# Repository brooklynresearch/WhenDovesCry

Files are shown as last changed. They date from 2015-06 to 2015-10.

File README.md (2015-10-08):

# ToniDove
Robotic Control and Communication.  

## OSC Messaging
The OSC messaging protocol to control the servos.
The current two messages to control the shoulder of the robot arm are `/sPitch` and `/sRoll`.  The Pitch message controlling the base rotation (single servo), and the Roll message controlling the swing angle (two servos).  Each message requires two integer arguments.  
### Arguments
`servoPosition` which has a range of 0 - 2047
 `servoSpeed` which has a range of 1 - inf. 
 `servoSpeed` is roughly in milliseconds and the value given is the amount of time you gave to go from currentPosition to the previously supplied servePosition (i.e. the larger the value given, the slower it will move)
### OSC Message Orientation
```{r, engine='bash', count_lines}
/sPitch servoPosition servoSpeed
/sRoll servoPosition servoSpeed
```
### OSC Example
```{r, engine='bash', count_lines}
/sPitch 512 18
/sRoll 1024 100
```
Current IP address is 192.168.0.200
Current listening PORT is 12345

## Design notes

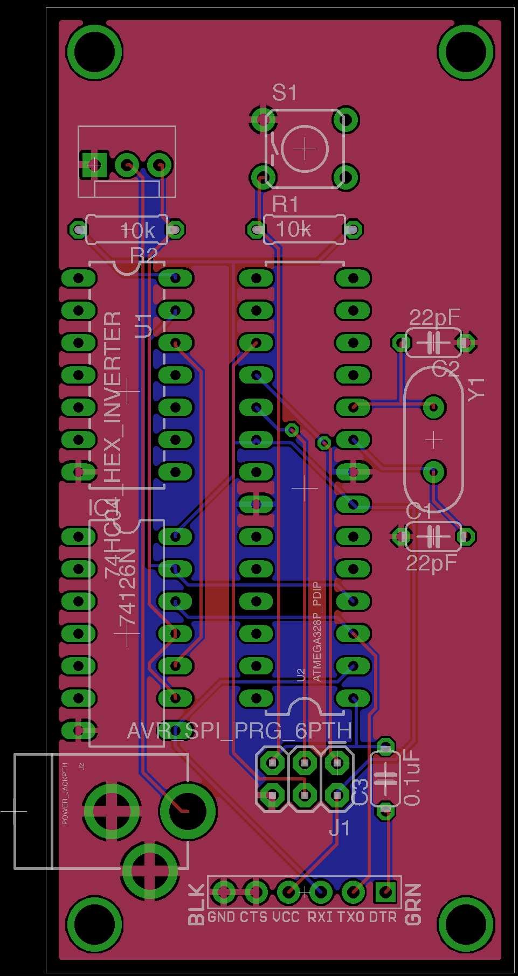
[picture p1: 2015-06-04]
ServoControl/Eagle/Arduino/Preliminary/DynamixelController_PreliminaryDesign.png

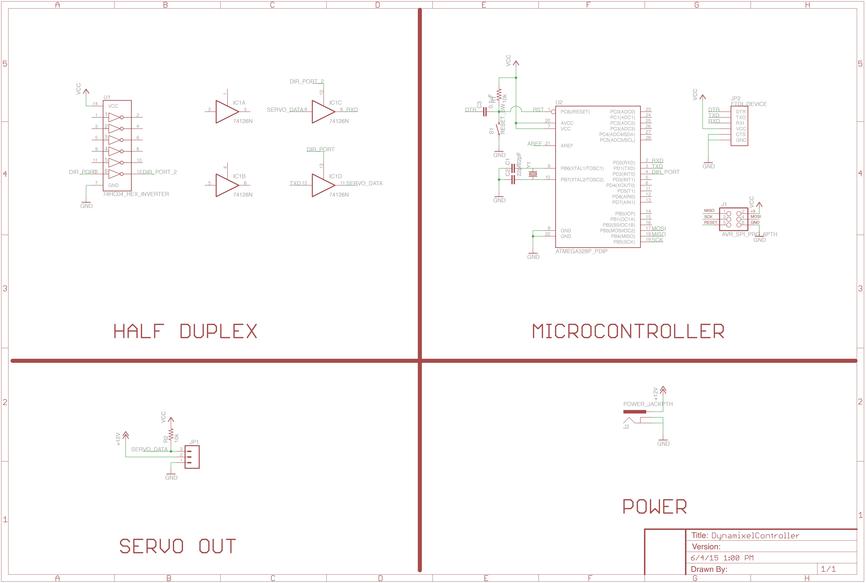
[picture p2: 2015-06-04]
ServoControl/Eagle/Arduino/Preliminary/DynamixelController_PreliminarySchematic.png

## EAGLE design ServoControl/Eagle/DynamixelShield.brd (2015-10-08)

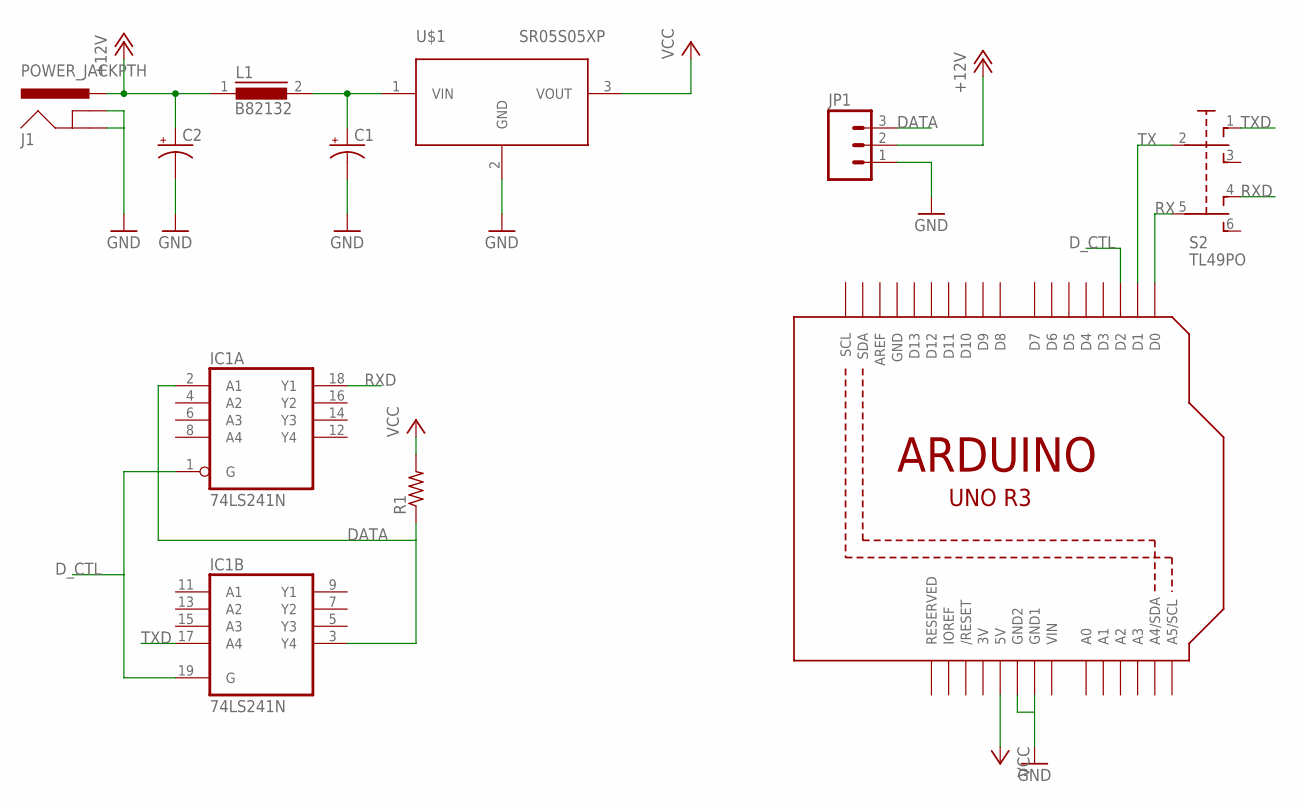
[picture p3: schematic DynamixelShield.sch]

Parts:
C1, C2: CPOL-USE3.5-10; E3,5-10
IC1: 74LS241N; DIL20
J1: POWER_JACKPTH; POWER_JACK_PTH
JP1: M031X03_NO_SILK; 1X03_NO_SILK
L1: B82132; SUKW2-22
R1: R-US_0204/7; 0204/7
S2: TL49PO; TL4XPO
U1: ARDUINOR3-DIMENSION; ARDUINOR3
U$1: SR05S05XP; XP_3PIN_SIP

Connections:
3V: U1.3V
+12V: C2.+, J1.PWR, JP1.2, L1.1
DATA: IC1.2 (A1), IC1.3 (Y4), JP1.3, R1.1
D_CTL: IC1.1 (G), IC1.19 (G), U1.D2
GND: C1.-, C2.-, IC1.10 (GND), J1.GND, J1.GNDBREAK, JP1.1, U1.GND, U1.GND1, U1.GND2, U$1.2 (GND)
unnamed: C1.+, L1.2, U$1.1 (VIN)
RX: S2.5 (P1), U1.D0
RXD: IC1.18 (Y1), S2.4 (O1)
TX: S2.2, U1.D1
TXD: IC1.17 (A4), S2.1 (O)
VCC: IC1.20 (VCC), R1.2, U1.5V, U$1.3 (VOUT)
VIN: U1.VIN

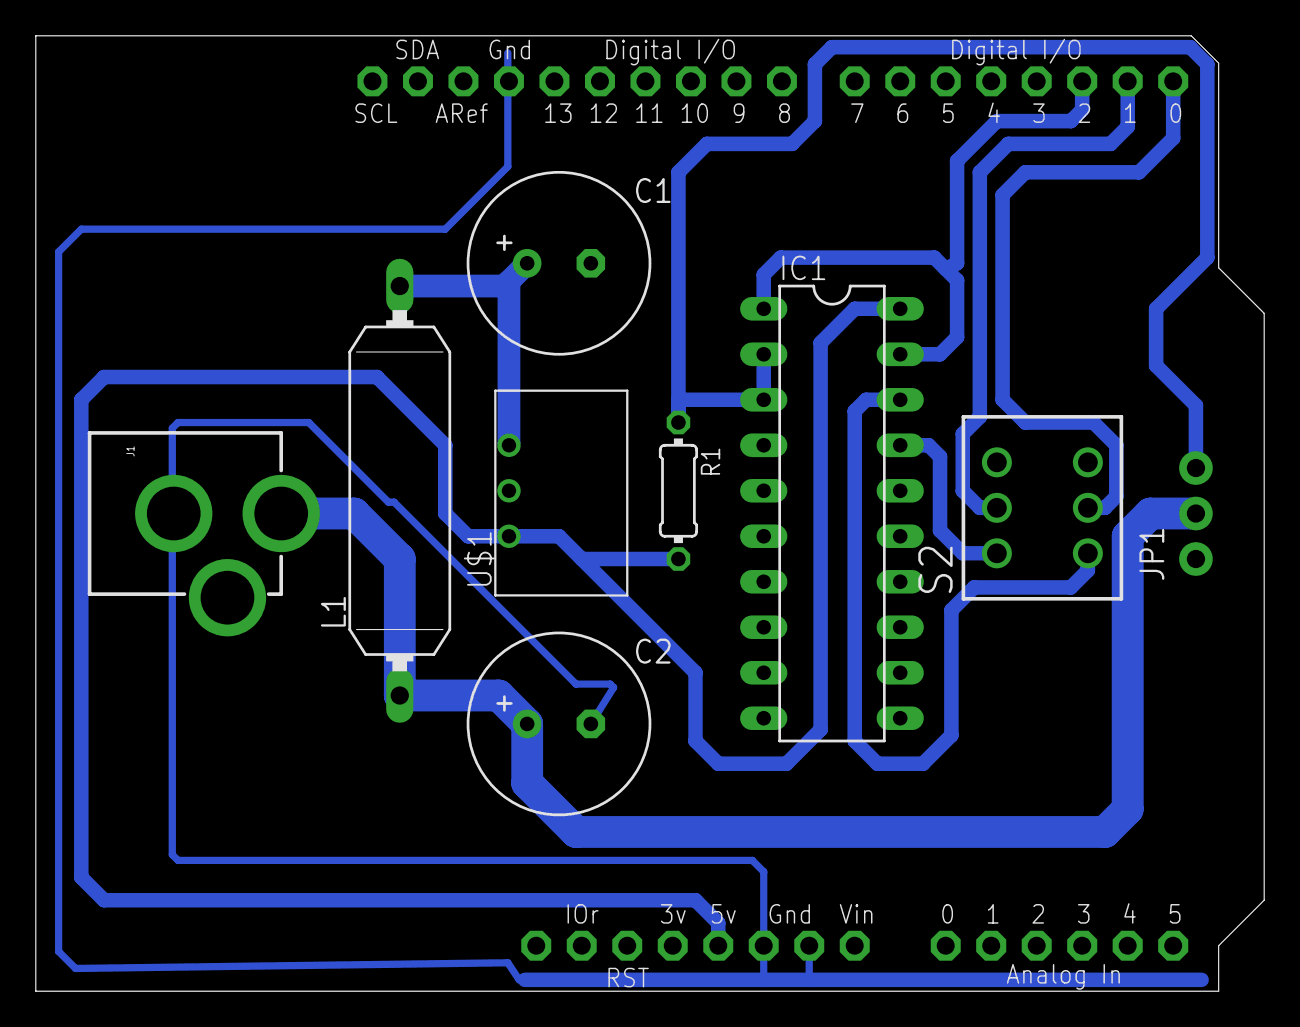
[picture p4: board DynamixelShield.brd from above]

Board: 2 copper layers, 68.6 x 53.3 mm, 10 parts (0 on the bottom side), 10 nets.

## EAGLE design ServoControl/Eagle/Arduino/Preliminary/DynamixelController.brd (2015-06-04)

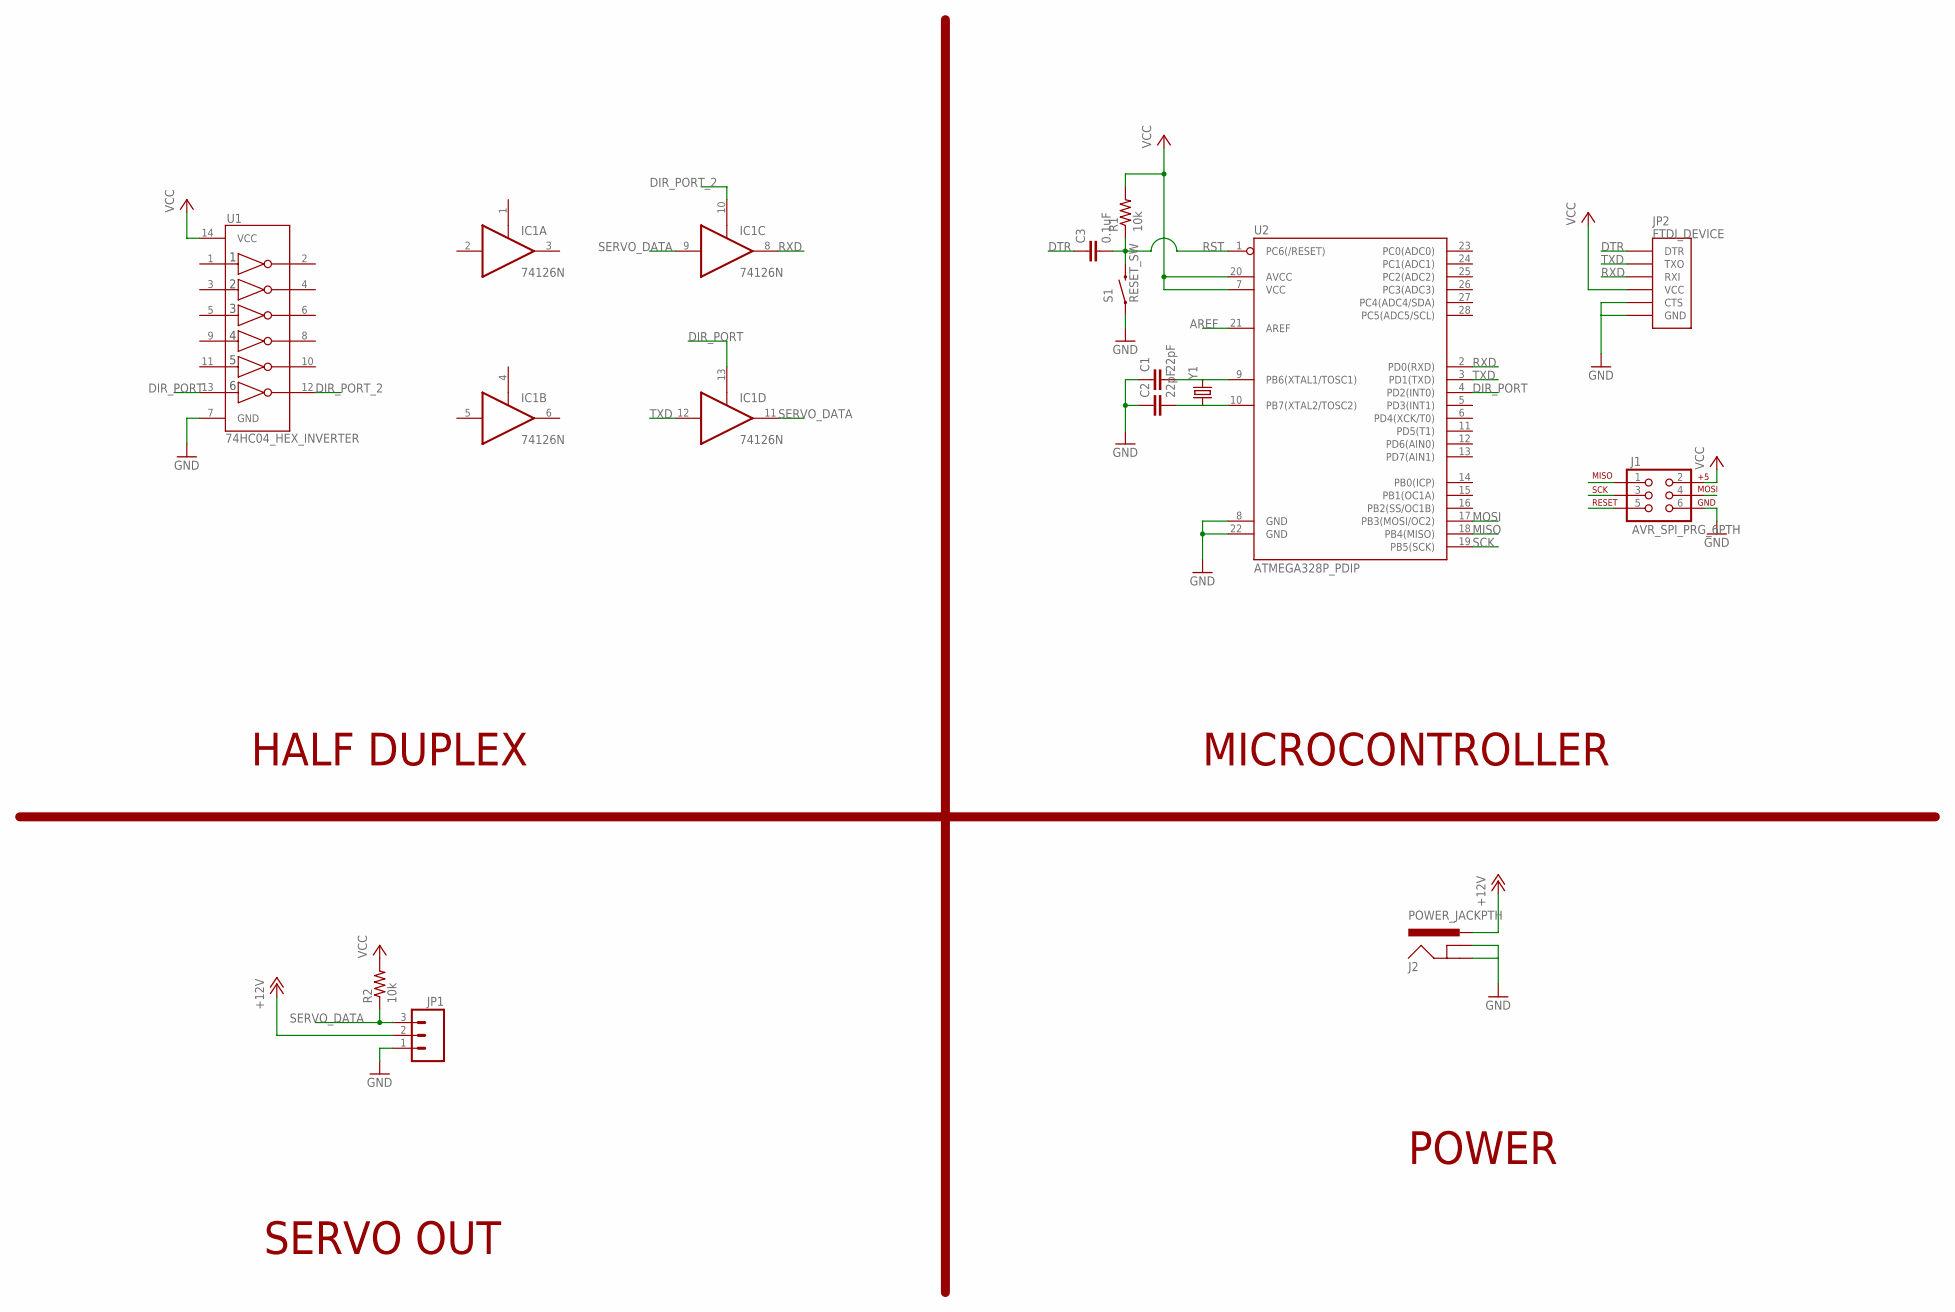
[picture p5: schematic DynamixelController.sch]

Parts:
C1, C2: 22pF; C050-024X044
C3: 0.1uF; C050-024X044
IC1: 74126N; DIL14
J1: AVR_SPI_PRG_6PTH; 2X3
J2: POWER_JACKPTH; POWER_JACK_PTH
JP1: M03POLAR; MOLEX-1X3
JP2: FTDI_DEVICE; FTDI_DEVICE_SIDE
R1, R2: 10k; 0207/7
S1: RESET_SW; TACTILE-PTH
U1: 74HC04_HEX_INVERTER; DIL14
U2: ATMEGA328P_PDIP; DIL28-3
Y1: CRYSTALHC49US; HC49US

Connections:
+12V: J2.PWR, JP1.2
AREF: U2.21 (AREF)
DIR_PORT: IC1.13 (OE), U1.13 (6A), U2.4 (PD2(INT0))
DIR_PORT_2: IC1.10 (OE), U1.12 (6Y)
DTR: C3.1, JP2.P$1 (DTR)
GND: C1.1, C2.1, IC1.7 (GND), J1.6, J2.GND, J2.GNDBREAK, JP1.1, JP2.P$5 (CTS), JP2.P$6 (GND), S1.1, U1.7 (GND), U2.8 (GND), U2.22 (GND)
MISO: J1.1, U2.18 (PB4(MISO))
MOSI: J1.4, U2.17 (PB3(MOSI/OC2))
unnamed: C1.2, U2.9 (PB6(XTAL1/TOSC1)), Y1.2
unnamed: C2.2, U2.10 (PB7(XTAL2/TOSC2)), Y1.1
RST: C3.2, J1.5, R1.1, S1.3 (2), U2.1 (PC6(/RESET))
RXD: IC1.8 (O), JP2.P$3 (RXI), U2.2 (PD0(RXD))
SCK: J1.3, U2.19 (PB5(SCK))
SERVO_DATA: IC1.9 (I), IC1.11 (O), JP1.3, R2.1
TXD: IC1.12 (I), JP2.P$2 (TXO), U2.3 (PD1(TXD))
VCC: IC1.14 (VCC), J1.2, JP2.P$4 (VCC), R1.2, R2.2, U1.14 (VCC), U2.7 (VCC), U2.20 (AVCC)

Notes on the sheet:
MICROCONTROLLER
HALF DUPLEX
SERVO OUT
POWER

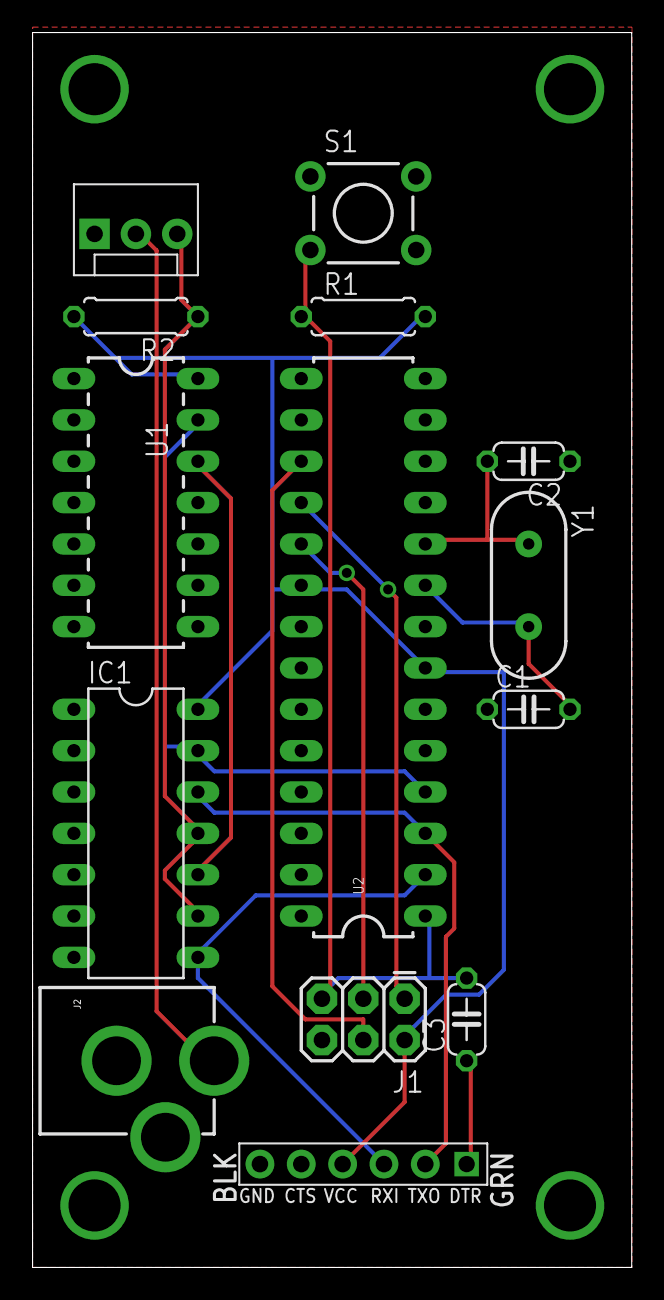
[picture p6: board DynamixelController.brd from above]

Board: 2 copper layers, 36.8 x 75.9 mm, 14 parts (0 on the bottom side), 15 nets.

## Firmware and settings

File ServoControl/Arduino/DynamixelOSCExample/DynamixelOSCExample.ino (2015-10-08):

/*  
DYNAMIXEL EASER EXAMPLE
by: Ezer Longinus
June 2015

This library is based on todbot ServoEaser library for standard Servos.
The library is just ported to work with Dynamixel Servos.

This example moves up to three servos to the list of positions in the "moves" array.

*/

//INCLUDE FILES
#include <SPI.h>
#include <Wire.h>
#include <Dynamixel_Serial.h>       // Library needed for dynamixel servos
#include <DynamixelEaser.h>         // Library needed for easing the dynamixels
#include <SoftwareSerial.h>         // Library needed for software serial
#include <Ethernet.h>
#include <EthernetUdp.h>
#include <OscUDP.h>

/*------------ ETHERNET SETUP ---------------*/
byte arduionMac[] = { 0x90, 0xA2, 0xDA, 0x0F, 0x85, 0x2A };
// listeningIP ==  SHIELD initialization IP
IPAddress arduinoIP(192,168,0,200); // you need to set this
// listening -- port
unsigned int arduinoPort = 12345;      // local port to listen on
// speaking 
// set up our destination NODE
NetAddress myComputer;
IPAddress myComputerIP(192,168,0,124); 
int myComputerPort = 12346;
// setup a UDP object
EthernetUDP UDP;
/*-------------------------------------------*/

/*-------------- OSC SETUP ------------------*/
// OUR OSC MESSAGE OBJECT
OscUDP etherOSC;  
// Various osc messages we'll be prepending and sending back to 
// the main computer
OscMessage shoulderPitchMsg("/Pos/sPitch/");
OscMessage shoulderRollMsg("/Pos/sRoll/");
OscMessage elbowPitchMsg("/Pos/ePitch/");
OscMessage elbowYawMsg("/Pos/eYaw/");
/*-------------------------------------------*/

//DEFINE STATEMENTS
#define SERVO_ID_1 0x01               // ID of which we will set Dynamixel Servo 1 to 
#define SERVO_ID_2 0x02               // ID of which we will set Dynamixel Servo 2 to
#define SERVO_ID_3 0x03               // ID of which we will set Dynamixel Servo 3 to
#define CONTROL_PIN 0x02              // This is data control pin.  This is for converting full to half duplex serial
#define SHOULDER_PITCH 0x01               // ID of which we will set Dynamixel Servo 1 to 
#define SHOULDER_ROLL_1 0x02               // ID of which we will set Dynamixel Servo 2 to
#define SHOULDER_ROLL_2 0x03               // ID of which we will set Dynamixel Servo 3 to
#define CONTROL_PIN 0x02              // This is data control pin.  This is for converting full to half duplex serial
#define SERVO_BAUD 57600
#define CW_LIMIT_ANGLE 0x001        // lowest clockwise angle is 1, as when set to 0 it set servo to wheel mode
#define CCW_LIMIT_ANGLE 0xFFF       // Highest anit-clockwise angle is 0XFFF, as when set to 0 it set servo to wheel mode

//MOVES LIST
int listLength = 3;
int servoCurrentMove[3][2] = {{0,0},{0,0},{0,0}};

//INITIALIZE SOFTWARE SERIAL - FOR DEBUGGING
SoftwareSerial mySerial(8, 9);    // RX, TX for software serial

//INITIALIZE EXTERNAL INPUTS AND OUTPUTS
const int ledPin   = 13; 
const int buttonPin = 3;
boolean buttonState = false;
boolean firstTime = true;

int servoFrameMillis = 1;  // minimum time between servo updates

DynamixelEaser shoulderPitchServo;
DynamixelEaser shoulderRollServo1;
DynamixelEaser shoulderRollServo2;

void setup() {
  //Set baud rate for debug serial
  mySerial.begin(57600);
  mySerial.println("Starting Debugger");
  
  // Initialize Ethernets
  Ethernet.begin(arduionMac ,arduinoIP);
  
  // start UDP object, listening on port listeningPort
  UDP.begin(arduinoPort);
  // set up our communication protocol
  // pass the UDP object to OSC
  etherOSC.begin(UDP);
  // define our destination location
  myComputer.set(myComputerIP, myComputerPort);
  
  //INITIALIZE SERVO MOTORS
  shoulderPitchServo.init();
  //Assign servos to their ids and frame rate
  shoulderPitchServo.begin(SHOULDER_PITCH, servoFrameMillis);   // Move servo to angle 1(0.088 degree) at speed 100
  shoulderRollServo1.begin(SHOULDER_ROLL_1, servoFrameMillis);   // Move servo to angle 1(0.088 degree) at speed 100
  shoulderRollServo2.begin(SHOULDER_ROLL_2, servoFrameMillis);
  
  shoulderPitchServo.reset();
  shoulderRollServo1.reset();
  shoulderRollServo2.reset();

  //set buttonPin to digital input
  pinMode(buttonPin, INPUT_PULLUP);
  //send message to debug serial so we know we're up and running
  mySerial.println("Dynamixel Example: ");
  mySerial.println("Move one dynamixel servo back and forth");
//  servo.setEasingFunc(easeOut);
//  servo2.setEasingFunc(easeOut);
//  servo3.setEasingFunc(easeOut);
  mySerial.print("IP:  ");
  printMyIP();
}

void loop() {

  shoulderPitchServo.update();
  shoulderRollServo1.update();
  shoulderRollServo2.update();
  
  if( shoulderPitchServo.hasArrived() || shoulderRollServo1.hasArrived() ) { 
      printAllServoPositions();
  }

  // important! non-blocking listen routine
  etherOSC.listen();  // if there is data waiting, this will trigger OSC EVENT
}

void printAllServoPositions(){
 mySerial.print("SHOULDER_PITCH: "); 
 mySerial.print(shoulderPitchServo.getCurrPos()); 
 mySerial.print("    SHOULDER_ROLL: "); 
 mySerial.println(shoulderRollServo1.getCurrPos()); 

}

/*--------------- DISPLAY IP ----------------*/
void printMyIP(){
  mySerial.print("IP:");
  mySerial.print(arduinoIP[0]);
  mySerial.print(".");
  mySerial.print(arduinoIP[1]);
  mySerial.print(".");
  mySerial.print(arduinoIP[2]);
  mySerial.print(".");
  mySerial.println(arduinoIP[3]);
}
/*-------------------------------------------*/

void singleServoMove(OscMessage &m){
  int servPos, servSpeed;
  servPos = m.getInt(0);
  servSpeed = m.getInt(1);
  shoulderPitchServo.easeTo(servPos, servSpeed);
  
  mySerial.print("ID: 1");mySerial.print("  POS: ");mySerial.print(servPos);mySerial.print("  SPD: ");mySerial.println(servSpeed);
}

void doubleServoMove(OscMessage &m){
  int servPos, servSpeed;
  servPos = m.getInt(0);
  servSpeed = m.getInt(1);
  shoulderRollServo1.easeTo(servPos, servSpeed);
  shoulderRollServo2.easeTo(servPos, servSpeed);
  
  mySerial.print("ID: 2,3");mySerial.print("  POS: ");mySerial.print(servPos);mySerial.print("  SPD: ");mySerial.println(servSpeed);

}

/*------------ OSC LISTENER -----------------*/
void oscEvent(OscMessage &m) { // *note the & before msg
  //lcd.setCursor(0,1);
  //lcd.print("Message Received");
  // receive a message 
  mySerial.println("got a message");
  // in arduino, we plug events in the EVENT method
  m.plug("/sPitch", singleServoMove); 
  m.plug("/sRoll", doubleServoMove);
}
/*-------------------------------------------*/

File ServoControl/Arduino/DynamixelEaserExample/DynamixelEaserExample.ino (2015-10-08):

/*  
DYNAMIXEL EASER EXAMPLE
by: Ezer Longinus
June 2015

This library is based on todbot ServoEaser library for standard Servos.
The library is just ported to work with Dynamixel Servos.

This example moves up to three servos to the list of positions in the "moves" array.

*/

//INCLUDE FILES
#include <SPI.h>
#include <Wire.h>
#include <Adafruit_GFX.h>
#include <Adafruit_SSD1306.h>
#include <Dynamixel_Serial.h>       // Library needed for dynamixel servos
#include <DynamixelEaser.h>         // Library needed for easing the dynamixels
#include <SoftwareSerial.h>         // Library needed for software serial

#define OLED_RESET 3
Adafruit_SSD1306 display(OLED_RESET);

#define NUMFLAKES 10
#define XPOS 0
#define YPOS 1
#define DELTAY 2

#define LOGO16_GLCD_HEIGHT 16 
#define LOGO16_GLCD_WIDTH  16 

#if (SSD1306_LCDHEIGHT != 32)
#error("Height incorrect, please fix Adafruit_SSD1306.h!");
#endif

//DEFINE STATEMENTS
#define SERVO_ID_1 0x01               // ID of which we will set Dynamixel Servo 1 to 
#define SERVO_ID_2 0x02               // ID of which we will set Dynamixel Servo 2 to
#define SERVO_ID_3 0x03               // ID of which we will set Dynamixel Servo 3 to
#define CONTROL_PIN 0x02              // This is data control pin.  This is for converting full to half duplex serial

//MOVES LIST
int listLength = 3;
int shoulderMoves[3] = {10, 1023, 2047};
int upperArmMoves[3] = {10, 2047, 10};
int index = 0;

//INITIALIZE SOFTWARE SERIAL - FOR DEBUGGING
SoftwareSerial mySerial(8, 9);    // RX, TX for software serial

//INITIALIZE EXTERNAL INPUTS AND OUTPUTS
const int ledPin   = 13; 
const int buttonPin = 3;
boolean buttonState = false;
boolean firstTime = true;

int servoFrameMillis = 5;  // minimum time between servo updates

//INITIALIZE SERVO MOTORS
DynamixelEaser servo;
DynamixelEaser servo2;
DynamixelEaser servo3;

void setup() {
  //Set baud rate for debug serial
  mySerial.begin(57600);
  mySerial.println("Starting Debugger");
  
  // by default, we'll generate the high voltage from the 3.3v line internally! (neat!)
  //display.begin(SSD1306_SWITCHCAPVCC, 0x3C);  // initialize with the I2C addr 0x3C (for the 128x32)
  // init done
  
  // Show image buffer on the display hardware.
  // Since the buffer is intialized with an Adafruit splashscreen
  // internally, this will display the splashscreen.
  //display.display();
  
  //Set default baud rate and control pin for all servos.  
  //Only need to call init once.  Any servo will do.  Just need to establish
  //baud and control pin.
  //DEFAULT BAUD = 1000000 :: DEFAULT CONTROL PIN = 2
  servo.init();
  //Assign servos to their ids and frame rate
  servo.begin(SERVO_ID_1, servoFrameMillis);
  servo2.begin(SERVO_ID_2, servoFrameMillis);
  servo3.begin(SERVO_ID_3, servoFrameMillis);
  //servo.easeTo(10, 2000);
  //set buttonPin to digital input
  pinMode(buttonPin, INPUT_PULLUP);
  //send message to debug serial so we know we're up and running
  mySerial.println("Dynamixel Example: ");
  mySerial.println("Move one dynamixel servo back and forth");
//  servo.setEasingFunc(easeOut);
//  servo2.setEasingFunc(easeOut);
//  servo3.setEasingFunc(easeOut);
}

void loop() {
  //Update the position/speed of the servos
  servo.update();
  servo2.update();
  servo3.update();
  
  buttonState = digitalRead(buttonPin);

  if( servo.hasArrived() || servo2.hasArrived()) { 
    mySerial.print("Running: ");mySerial.println(servo.isRunning());
    //index to the next position on the moves array
    index = (index + 1) % listLength;
    //debug to let us know we've arrived
    mySerial.print("ServoEaser arrived at ");mySerial.print(shoulderMoves[index]);mySerial.println(" degrees,");
    //send the next position to the servos.
    servo.easeTo( shoulderMoves[index], 2000 );
    servo2.easeTo( upperArmMoves[index], 2000 );
    servo3.easeTo( upperArmMoves[index], 2000 );
  } 
}

float easeIn (float t,float b , float c, float d) {
	return c - easeOut (d-t, 0, c, d) + b;
}
float easeOut(float t,float b , float c, float d) {
	if ((t/=d) < (1/2.75f)) {
		return c*(7.5625f*t*t) + b;
	} else if (t < (2/2.75f)) {
		float postFix = t-=(1.5f/2.75f);
		return c*(7.5625f*(postFix)*t + .75f) + b;
	} else if (t < (2.5/2.75)) {
			float postFix = t-=(2.25f/2.75f);
		return c*(7.5625f*(postFix)*t + .9375f) + b;
	} else {
		float postFix = t-=(2.625f/2.75f);
		return c*(7.5625f*(postFix)*t + .984375f) + b;
	}
}

float easeInOut(float t,float b , float c, float d) {
	if (t < d/2) return easeIn (t*2, 0, c, d) * .5f + b;
	else return easeOut (t*2-d, 0, c, d) * .5f + c*.5f + b;
}

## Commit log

2015-06-04 Initial Push
    Initial Arduino sketch just for testing Dynamixel Servos. By no means
    complete, just a starting point.
2015-06-04 Preliminary Board Designs
    Preliminary schematics and layout for servo control using atmega328
    (Arduino). Still need better power distribution, sensors inputs, and
    limit switch inputs.
    [DynamixelController.brd, DynamixelController.sch]
2015-06-09 Easing Library Uploaded
    Used a servo easing library and ported it for dynamixels servos
    specifically. Added an example to move up to three servos from a list
    of positions.
2015-10-08 OSC Update
    Added initial OSC Firmware code, with necessary libraries, and readme
    file. Also included the eagle file to print the Arduino shield for
    controlling the Dynamixels.
    [DynamixelShield.brd, DynamixelShield.sch]

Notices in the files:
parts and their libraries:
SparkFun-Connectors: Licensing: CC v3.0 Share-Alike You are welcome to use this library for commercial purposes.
